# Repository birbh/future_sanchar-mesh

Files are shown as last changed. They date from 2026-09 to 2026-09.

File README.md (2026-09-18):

# future_sanchar-jaal

Future_sanchar-jaal is a custom, open-source digital walkie-talkie powered by ESP32-S3. Unlike traditional analog radios those suffer from static or require a central router to work, this device uses the ESP-NOW v2 protocol to create a direct p2p 2.4GHz network. 

## What makes it unique??
It is unique because it used i2s components alongside a massive 1440 bytes transmission buffer which helps to deliver a crisp voice with an ultra-low latency. Also it uses esp32-S3-wroom-1u which has ipex antenna connector in it which has drastically helped to increase the range of walkie talkie. It provides upto 800+ meters range under normal conditions and if with obstacles it provides upto 200 meters range. 

## Why I made it??

Recently my country Nepal suffered a devastating flood which ruined so many human lives. So I thought that if I could make a Lo-Ra walkie-talkie, I could warn the people using the walkie-talkie along the long distance. Also in Nepal, due to difficult geography, the cellular network coverage could be unreliable when trekking and traveling through rural areas. In conclusion, I made this walkie-talkie to solve the real-world problem and help communicate over long distances easily. 

## How to use it?
1. Turn on the slide switch on the front side of the walkie-talkie.
2. The LED will flash Blue when booting and OLED will display "Sanchar-Jaal Boot".
3. Once the screen displays "Talk!! I am Listening..", you are ready and connected to the network.
4. Then press and hold the Push to Talk button in the front then the led will turn RED, and the screen will display "Transmitting.....!". Then you should speak near the microphone grill.
5. We will have paired devices, so when one talks the LED will turn GREEN and audio will automatically play through the speaker in front.
6. If the walkie talkie glitches then there is reset button in the back why can press that to fix the walkie talkie.
7. If the battery finishes then you can charge it through usb c in the left of walkie talkie
8. You can adjust the volume also from the onboard potentiometer to make the desired volume.

## Assembly Instructions:
### 3d print enclosure:
- All cad files are provided in the github repo.
- there are 3 separate cad files to be printed top lid, bottom lid and the base.
- You should print those 3 files separately

### PCB & soldering:
- All required files are provided in Production folder inside pcb_sanchar.
- solder all the smd components first as indicated in silkscreen
- then solder the usb-c breakout board to its assembly place in the left of walkie talkie using a wire i.e connect In+ and In- of tp4056 to the breakout board VBUS and GND respectively.
- then secure all the components in their respective mounts as in CAD. 

### Flashing firmware:
- Connect your FDTI adapter to J1 programming header on the board.
- Open the firmware file in the arduino ide.
- Hit upload -- when the console says connecting hold the BOOT button in the pcb and Press and release the RESET button then release the boot button.
- Wait for upload to finish then press BOOT button to boot the device.
- Then to pair the two devices check the serial monitor and find the MAC-address of DEVICE 1 and paste it into the code for DEVICE 2 (and vice versa). 

## Assets:
### Cad Screenshots:
Screenshot 2026-09-18 at 1 24 17 PM
Screenshot 2026-09-18 at 1 24 32 PM
Screenshot 2026-09-18 at 1 24 58 PM
Screenshot 2026-09-18 at 1 25 28 PM

### CAD link:
fusion360 ::: [Sanchar-jaal-cad](https://a360.co/4xBj2PT)

### Pcb:
Screenshot 2026-09-18 at 1 17 54 PM
Screenshot 2026-09-18 at 1 18 21 PM
Screenshot 2026-09-18 at 1 18 38 PM

### Schematic:
Screenshot 2026-09-18 at 1 19 46 PM

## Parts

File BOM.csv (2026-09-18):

Id | Designator | Footprint | Quantity | Designation | Link | Price
1 | BT1 | JST_PH_S2B-PH-K_1x02_P2.00mm_Horizontal | 4 | Battery_Cell | https://shorturl.at/hIcLj | $18
2 | C1, C2, C5 | C_0805_2012Metric | 6 | 10µF | https://shorturl.at/dkd7K | $2.3
3 | C3, C4, C6 | C_0805_2012Metric | 6 | 100nf | https://shorturl.at/dkd7K | $2.3
4 | C7 | C_0805_2012Metric | 2 | 1µF | https://shorturl.at/dkd7K | $2.3
5 | D1 | LED_WS2812B_PLCC4_5.0x5.0mm_P3.2mm | 2 | WS2812B | https://shorturl.at/Q40h6 | $11
6 | J1 | FanPinHeader_1x04_P2.54mm_Vertical | 2 | Conn_01x04_Pin | https://shorturl.at/0AHKv | $7
7 | LS1 | JST_PH_S2B-PH-K_1x02_P2.00mm_Horizontal | 2 | Speaker | https://shorturl.at/RXhoH | $5
8 | M1 | INMP441_OMNIDIRECTIONAL_MICROPHONE_MODULE | 2 | INMP441 Microphone | https://h1.nu/1ydcw | $8
9 | R1 | R_0805_2012Metric | 2 | 100kΩ | https://h1.nu/1ydd0 | $1
10 | R2 | R_0805_2012Metric | 2 | 10kΩ | https://h1.nu/1ydd0 | $1
11 | RV1 | Potentiometer_Bourns_PTV09A-1_Single_Vertical | 2 | R_Potentiometer_MountingPin | https://h1.nu/1yddz | $2.9
12 | SW1, SW3-boot, SW4-reset | SW_Push_1P1T_NO_E-Switch_TL3301NxxxxxG | 6 | SW_Push | https://h1.nu/1ydel | $9
13 | SW2 | SW_Slide_SPDT_Straight_CK_OS102011MS2Q | 2 | SW_SPDT | https://h1.nu/1DZo9 | $4.5
14 | TP1 | TP4056-18650 | 2 | TP4056_cm | https://h1.nu/1DZoD | $3.5
15 | U1 | XCVR_ESP32-S3-WROOM-1U-N16R8 | 2 | ESP32-S3-WROOM-1U-N16R8 | https://h1.nu/1ydgw | $9.86
16 | U2 | ER_OLEDM0.91_1x-I2C | 2 | ER_OLEDM0.91_1x-I2C | https://h1.nu/1ydh5 | $6.88
17 | U3 | SOT-223-3_TabPin2 | 2 | AMS1117-3.3 | https://h1.nu/1DZr0 | $6
18 | U4 | TQFN-16-1EP_3x3mm_P0.5mm_EP1.23x1.23mm | 2 | MAX98357A | https://h1.nu/1ydjG | $2.65
19 |  |  | 2 | USB Type C Connector Board 3.1 Serial Basic Breakout Female | https://h1.nu/1DZtC | $4.99
20 |  |  | 2 | JST_PH | https://h1.nu/1DZvK | $.24
 | TOTAL |  |  |  |  | $108.42

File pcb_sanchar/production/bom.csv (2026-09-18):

Designator | Footprint | Quantity | Value | LCSC Part #
BT1 | JST_PH_S2B-PH-K_1x02_P2.00mm_Horizontal | 1 | Battery_Cell
C1, C2, C5 | 0805 | 3 | 10µF
C3, C4, C6 | 0805 | 3 | 100nf
C7 | 0805 | 1 | 1µF
D1 | LED_WS2812B_PLCC4_5.0x5.0mm_P3.2mm | 1 | WS2812B
J1 | FanPinHeader_1x04_P2.54mm_Vertical | 1 | Conn_01x04_Pin
LS1 | JST_PH_S2B-PH-K_1x02_P2.00mm_Horizontal | 1 | Speaker
M1 | INMP441_OMNIDIRECTIONAL_MICROPHONE_MODULE | 1 | INMP441 Microphone
R1 | 0805 | 1 | 100kΩ
R2 | 0805 | 1 | 10kΩ
RV1 | Potentiometer_Bourns_PTV09A-1_Single_Vertical | 1 | R_Potentiometer_MountingPin
SW1, SW3-BOOT, SW4-RESET | SW_Push_1P1T_NO_E-Switch_TL3301NxxxxxG | 3 | SW_Push
SW2 | SW_Slide_SPDT_Straight_CK_OS102011MS2Q | 1 | SW_SPDT
TP1 | TP4056-18650 | 1 | TP4056_cm
U1 | XCVR_ESP32-S3-WROOM-1U-N16R8 | 1 | ESP32-S3-WROOM-1U-N16R8
U2 | ER_OLEDM0.91_1x-I2C | 1 | ER_OLEDM0.91_1x-I2C
U3 | SOT-223-3_TabPin2 | 1 | AMS1117-3.3
U4 | TQFN-16-1EP_3x3mm_P0.5mm_EP1.23x1.23mm | 1 | MAX98357A

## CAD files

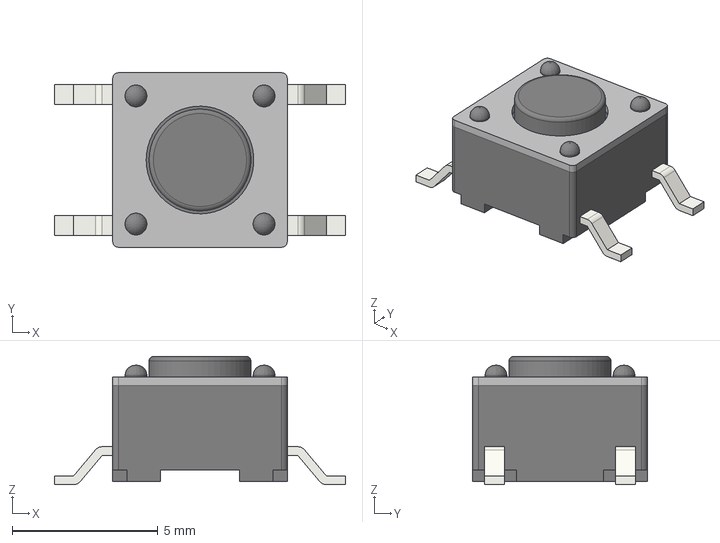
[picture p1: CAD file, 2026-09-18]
CAD/parts/SW_Push_1P1T_NO_E-Switch_TL3301NxxxxxG.step
10.0 x 6.00 x 4.40 mm

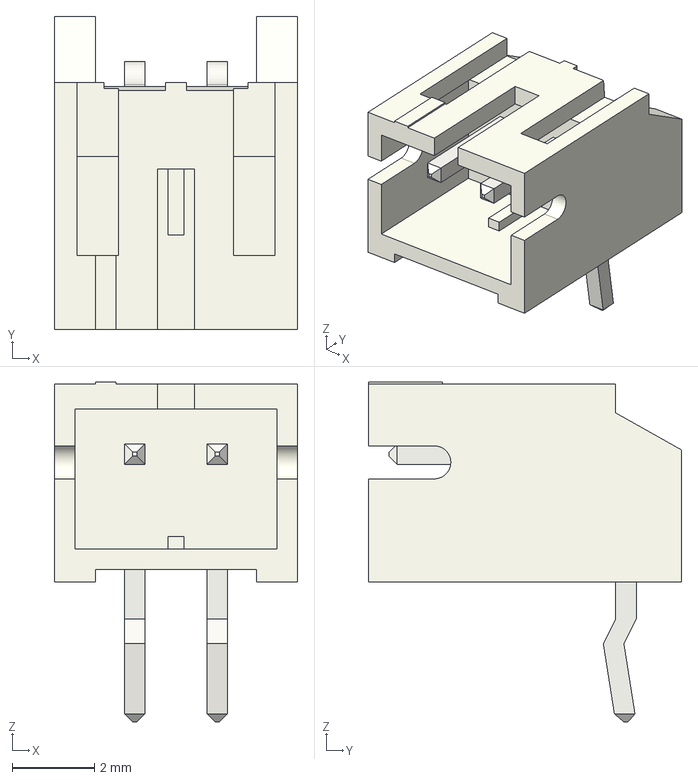
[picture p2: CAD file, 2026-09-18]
CAD/parts/JST_PH_S2B-PH-K_1x02_P2.00mm_Horizontal.step
5.90 x 7.60 x 8.25 mm

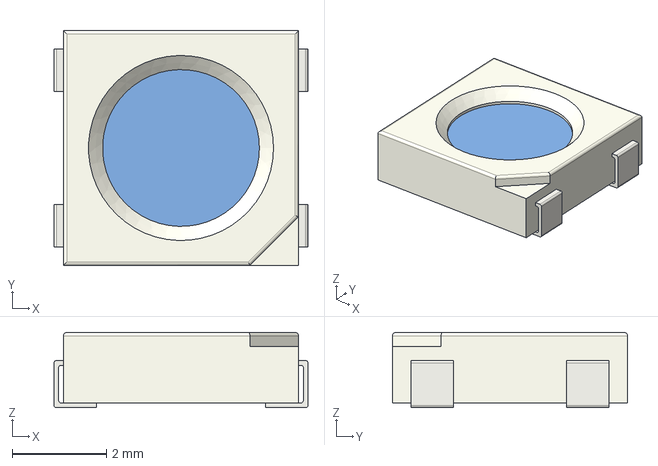
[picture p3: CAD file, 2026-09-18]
CAD/parts/LED_WS2812B_PLCC4_5.0x5.0mm_P3.2mm.step
5.40 x 5.00 x 1.60 mm

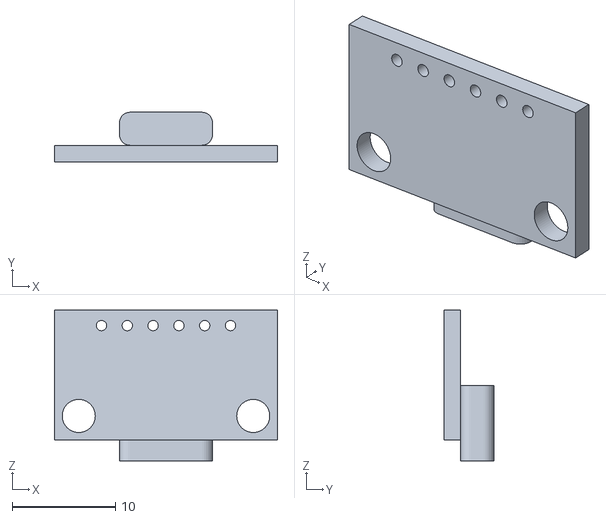
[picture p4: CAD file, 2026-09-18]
CAD/parts/usb-c-breakout.obj
21.6 x 4.80 x 14.6

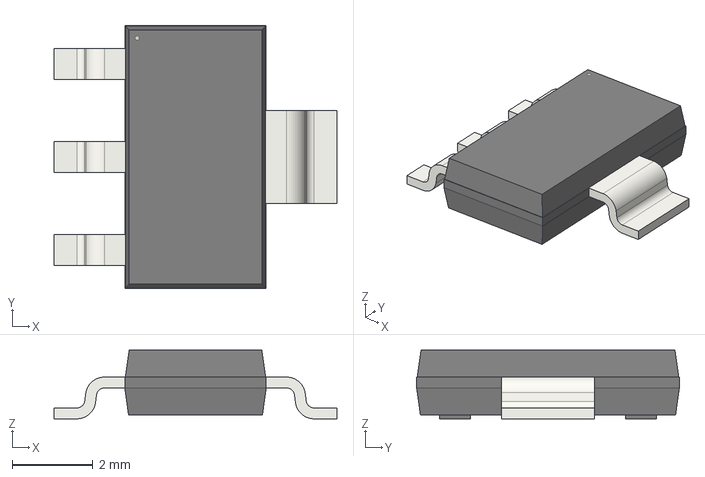
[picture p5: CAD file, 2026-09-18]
CAD/parts/SOT-223.step
7.00 x 6.50 x 1.70 mm

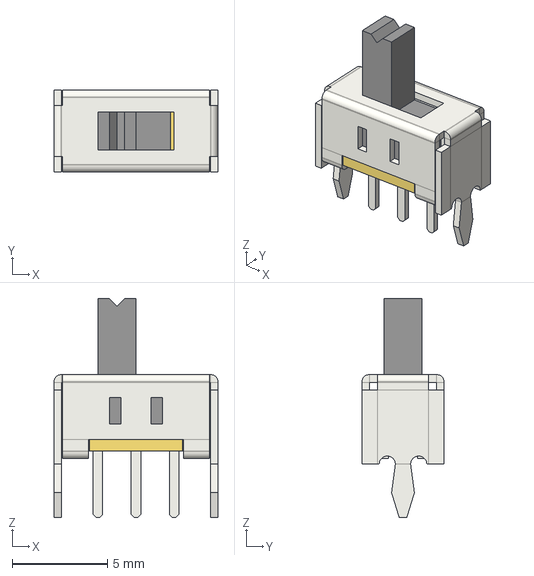
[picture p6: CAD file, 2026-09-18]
CAD/parts/SW_Slide_SPDT_Straight_CK_OS102011MS2Q.step
8.60 x 4.30 x 11.5 mm

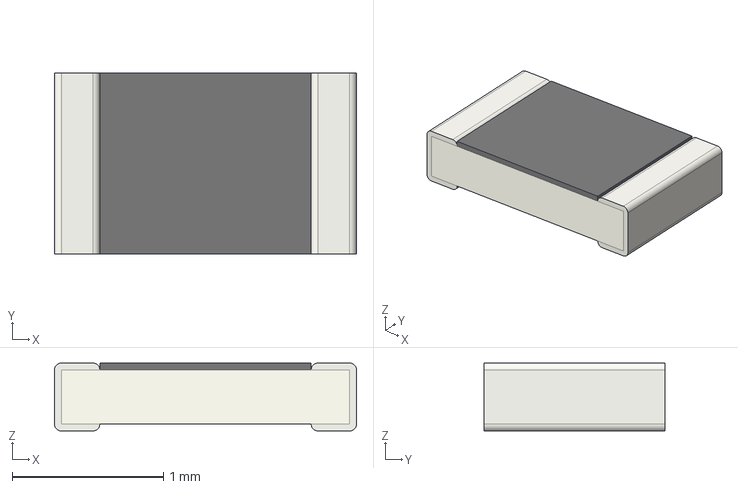
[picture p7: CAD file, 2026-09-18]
CAD/parts/R_0805_2012Metric.step
2.00 x 1.20 x 0.45 mm

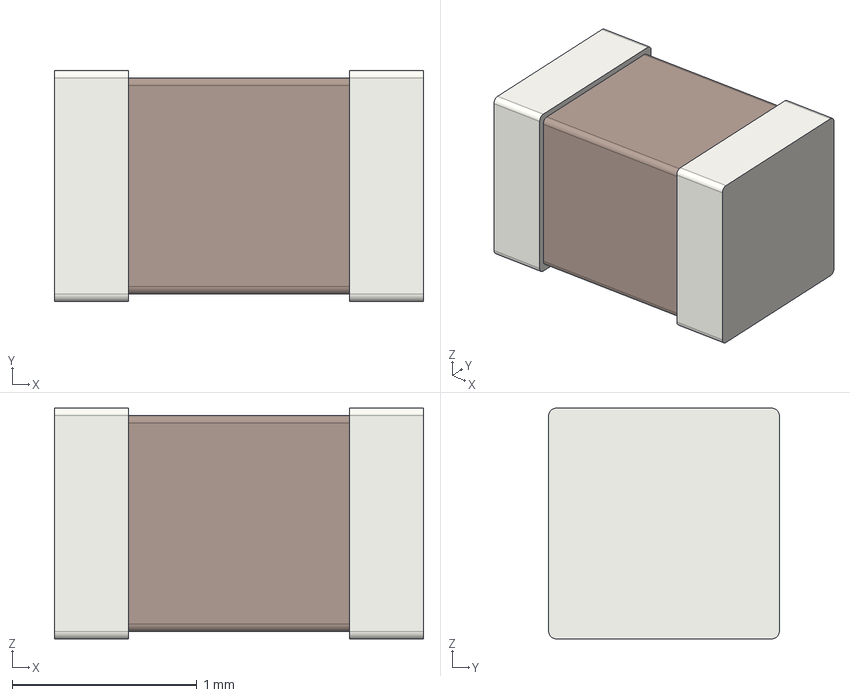
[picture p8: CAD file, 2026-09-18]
CAD/parts/C_0805_2012Metric.step
2.00 x 1.25 x 1.25 mm

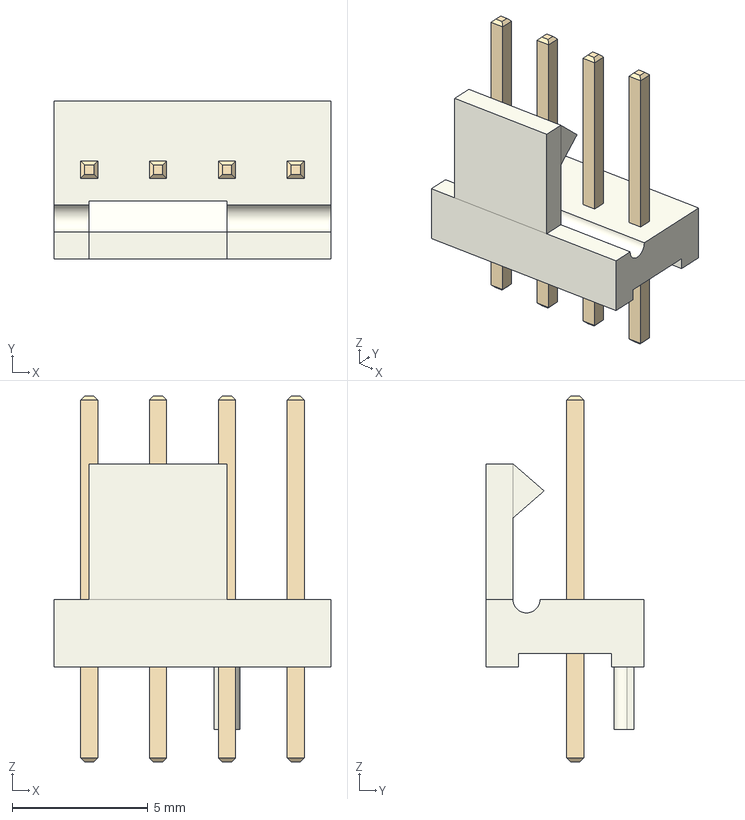
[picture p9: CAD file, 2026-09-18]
CAD/parts/FanPinHeader_1x04_P2.54mm_Vertical.step
10.2 x 5.84 x 13.5 mm

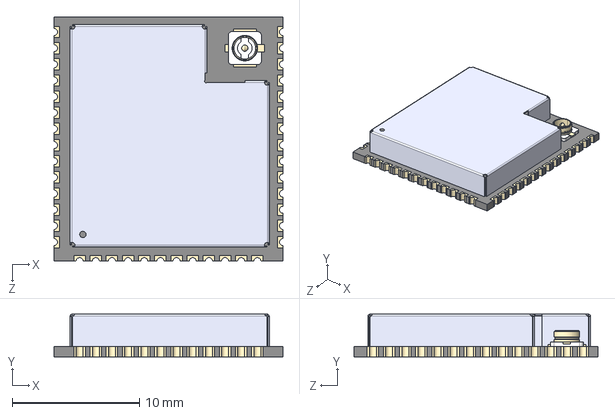
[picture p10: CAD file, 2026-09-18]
CAD/parts/ESP32-S3-WROOM-1U-N16R8.step
18.0 x 3.35 x 19.2 mm

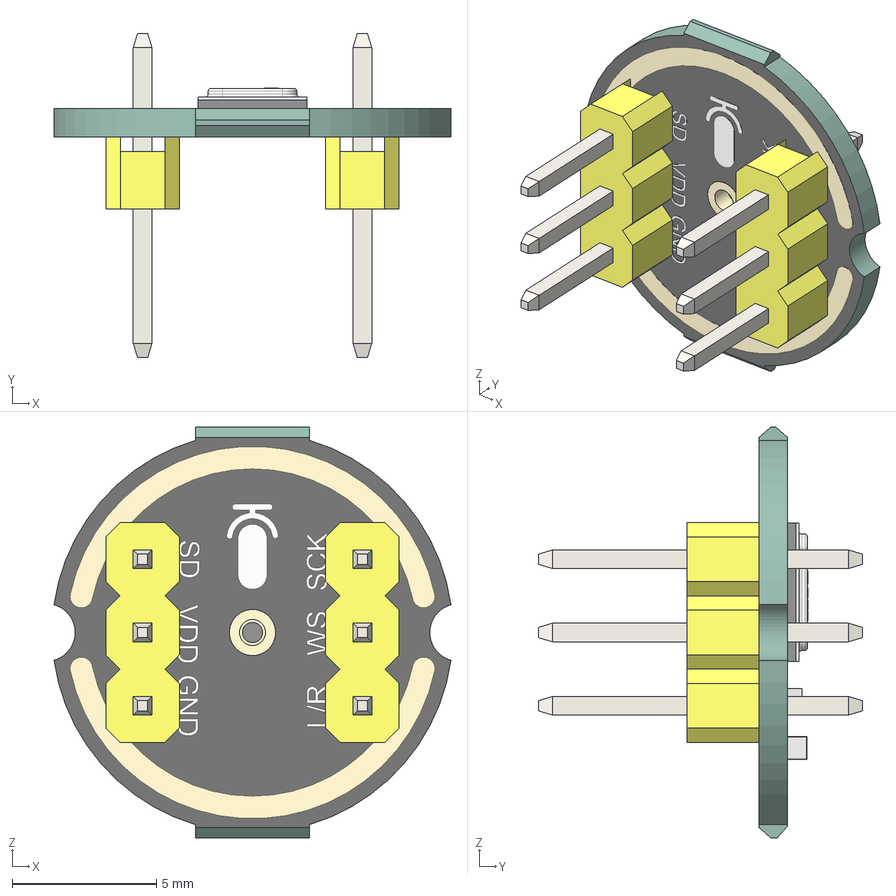
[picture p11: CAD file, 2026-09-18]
CAD/parts/INMP441 I2S Microphone Module v15.step
13.8 x 11.2 x 14.2 mm
0603 Resistor

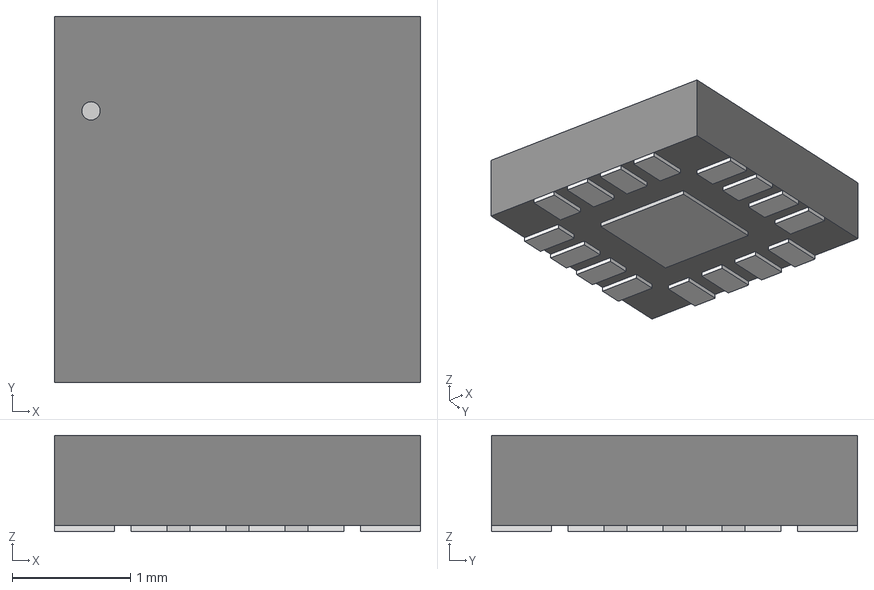
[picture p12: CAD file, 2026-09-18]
CAD/parts/21-0136I_T1633-4_MXM.step
3.10 x 3.10 x 0.815 mm

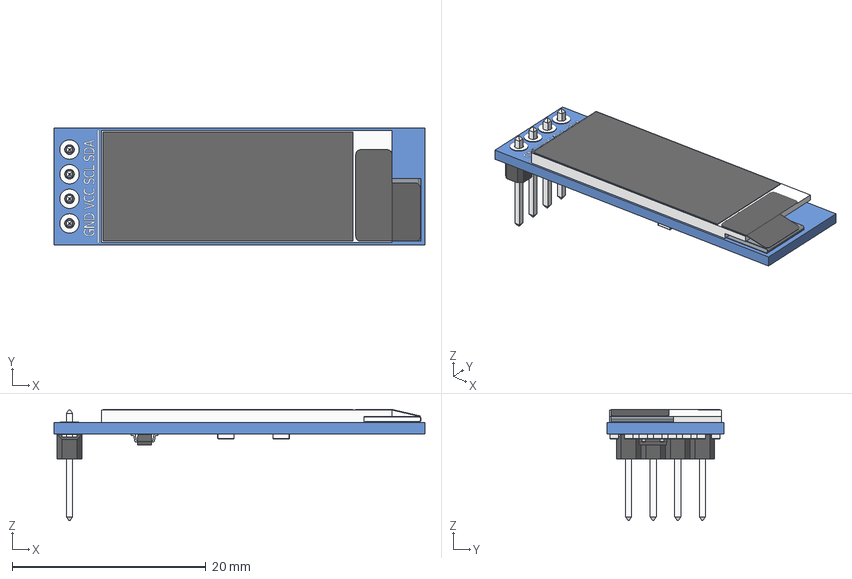
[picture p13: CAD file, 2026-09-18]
CAD/parts/OLED_0.91_128x32.stp
38.3 x 12.1 x 11.5 mm
OLED_0.91_128x32
Pin Header 4 x 1 TH 2.54mm Pitch
RESC-0603 x 13
2SD0601A

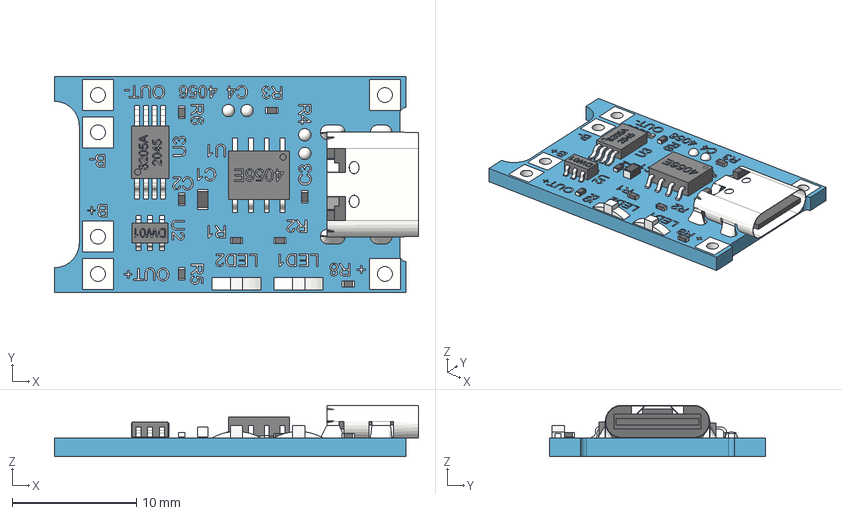
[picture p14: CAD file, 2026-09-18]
CAD/parts/TP4056_Charging_Module_Type_C.step
29.3 x 17.4 x 4.14 mm
board
USB_Type_C_Connector
8205A_2045
DW01-P
small1005_smd_resistor x 2
small1005_smd_resistor (1)
small1005_smd_capacitor
smd_capacitor
SOP-8_4056E
solder_dot_round
solder_dot_round (1)
solder_dot_round (2)
solder_dot_round (3)
small1005_smd_capacitor (1)
LED2
LED2 (1)
small1005_smd_resistor (2)
small1005_smd_resistor (4) x 2
soldering

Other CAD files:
CAD/3D print/back-lid.f3d
CAD/3D print/base.f3d
CAD/3D print/top-lid.f3d

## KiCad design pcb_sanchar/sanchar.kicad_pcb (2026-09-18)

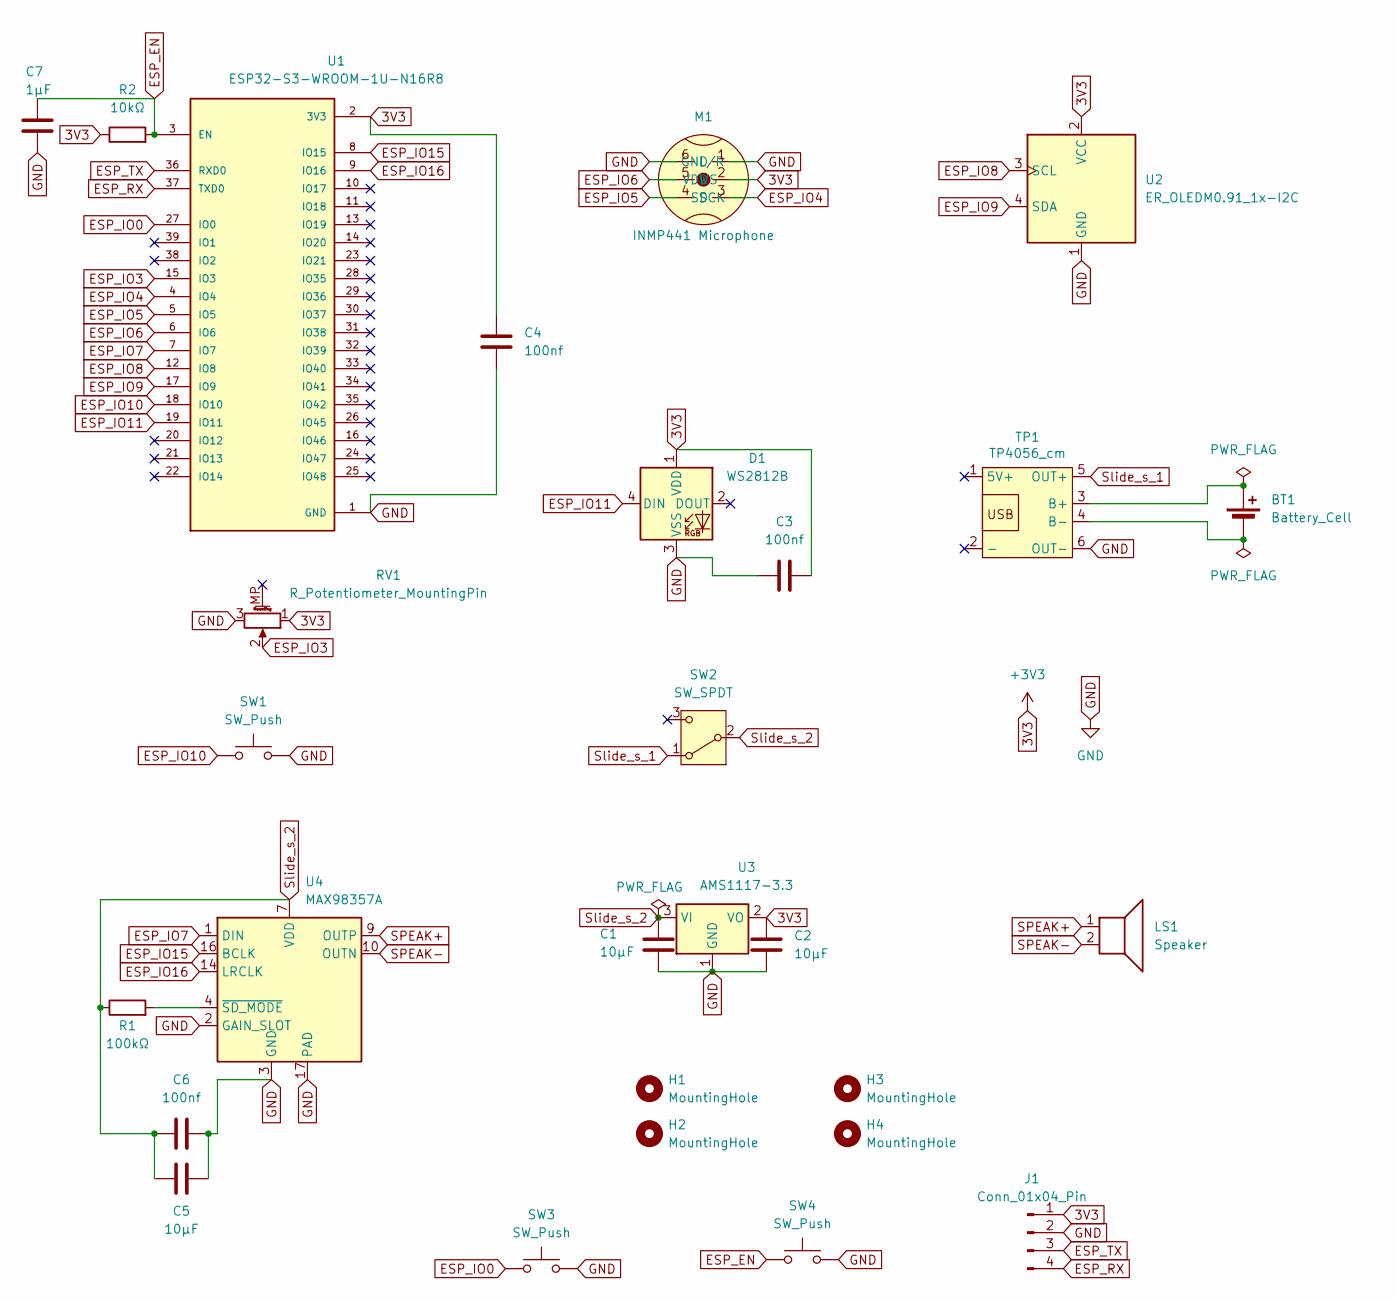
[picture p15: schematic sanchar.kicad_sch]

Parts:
BT1: Battery_Cell; JST_PH_S2B-PH-K_1x02_P2.00mm_Horizontal
C1, C2, C5: 10µF; C_0805_2012Metric
C3, C4, C6: 100nf; C_0805_2012Metric
C7: 1µF; C_0805_2012Metric
D1: WS2812B; LED_WS2812B_PLCC4_5.0x5.0mm_P3.2mm
H1, H2, H3, H4: MountingHole; MountingHole_3.2mm_M3
J1: Conn_01x04_Pin; FanPinHeader_1x04_P2.54mm_Vertical
LS1: Speaker; JST_PH_S2B-PH-K_1x02_P2.00mm_Horizontal
M1: INMP441 Microphone; INMP441_OMNIDIRECTIONAL_MICROPHONE_MODULE
R1: 100kΩ; R_0805_2012Metric
R2: 10kΩ; R_0805_2012Metric
RV1: R_Potentiometer_MountingPin; Potentiometer_Bourns_PTV09A-1_Single_Vertical
SW1, SW3, SW4: SW_Push; SW_Push_1P1T_NO_E-Switch_TL3301NxxxxxG
SW2: SW_SPDT; SW_Slide_SPDT_Straight_CK_OS102011MS2Q
TP1: TP4056_cm; TP4056-18650
U1: ESP32-S3-WROOM-1U-N16R8; XCVR_ESP32-S3-WROOM-1U-N16R8; PARTREV v1.1
U2: ER_OLEDM0.91_1x-I2C
U3: AMS1117-3.3; SOT-223-3_TabPin2
U4: MAX98357A; TQFN-16-1EP_3x3mm_P0.5mm_EP1.23x1.23mm

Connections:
3V3: C2.1, C3.2, C4.1, D1.1 (VDD), J1.1, M1.2 (VDD), R2.1, RV1.1, U1.2 (3V3), U2.2 (VCC), U3.2 (VO)
ESP_EN: C7.1, R2.2, SW4.1, U1.3 (EN); also elsewhere on the board
ESP_IO0: SW3.1, U1.27 (IO0); also elsewhere on the board
ESP_IO3: RV1.2, U1.15 (IO3)
ESP_IO4: M1.3 (SD), U1.4 (IO4)
ESP_IO5: M1.4 (SCK), U1.5 (IO5)
ESP_IO6: M1.5 (WS), U1.6 (IO6)
ESP_IO7: U1.7 (IO7), U4.1 (DIN)
ESP_IO8: U1.12 (IO8), U2.3 (SCL)
ESP_IO9: U1.17 (IO9), U2.4 (SDA)
ESP_IO10: SW1.1, U1.18 (IO10)
ESP_IO11: D1.4 (DIN), U1.19 (IO11)
ESP_IO15: U1.8 (IO15), U4.16 (BCLK)
ESP_IO16: U1.9 (IO16), U4.14 (LRCLK)
ESP_RX: J1.4, U1.37 (TXD0)
ESP_TX: J1.3, U1.36 (RXD0)
GND: C1.2, C2.2, C3.1, C4.2, C5.2, C6.2, C7.2, D1.3 (VSS), J1.2, M1.1 (GND), M1.6 (L/R), RV1.3, SW1.2, SW3.2, SW4.2, TP1.6 (OUT-), U1.1 (GND), U1.40 (GND), U1.41_1 (GND), U1.41_2 (GND), U1.41_3 (GND), U1.41_4 (GND), U1.41_5 (GND), U1.41_6 (GND), U1.41_7 (GND), U1.41_8 (GND), U1.41_9 (GND), U1.41_10, U1.41_11, U1.41_12, U1.41_13, U1.41_14, U1.41_15, U1.41_16, U1.41_17, U1.41_18, U1.41_19, U1.41_20, U1.41_21, U2.1 (GND), U3.1 (GND), U4.2 (GAIN_SLOT), U4.3 (GND), U4.11 (GND), U4.15 (GND), U4.17 (PAD); also elsewhere on the board
unnamed: BT1.1 (+), TP1.3 (B+)
unnamed: BT1.2 (-), TP1.4 (B-)
unnamed: R1.2, U4.4 (~SD_MODE)
SPEAK+: LS1.1, U4.9 (OUTP)
SPEAK-: LS1.2, U4.10 (OUTN)
Slide_s_1: SW2.1 (A), TP1.5 (OUT+)
Slide_s_2: C1.1, C5.1, C6.1, R1.1, SW2.2 (B), U3.3 (VI), U4.7 (VDD), U4.8 (VDD)

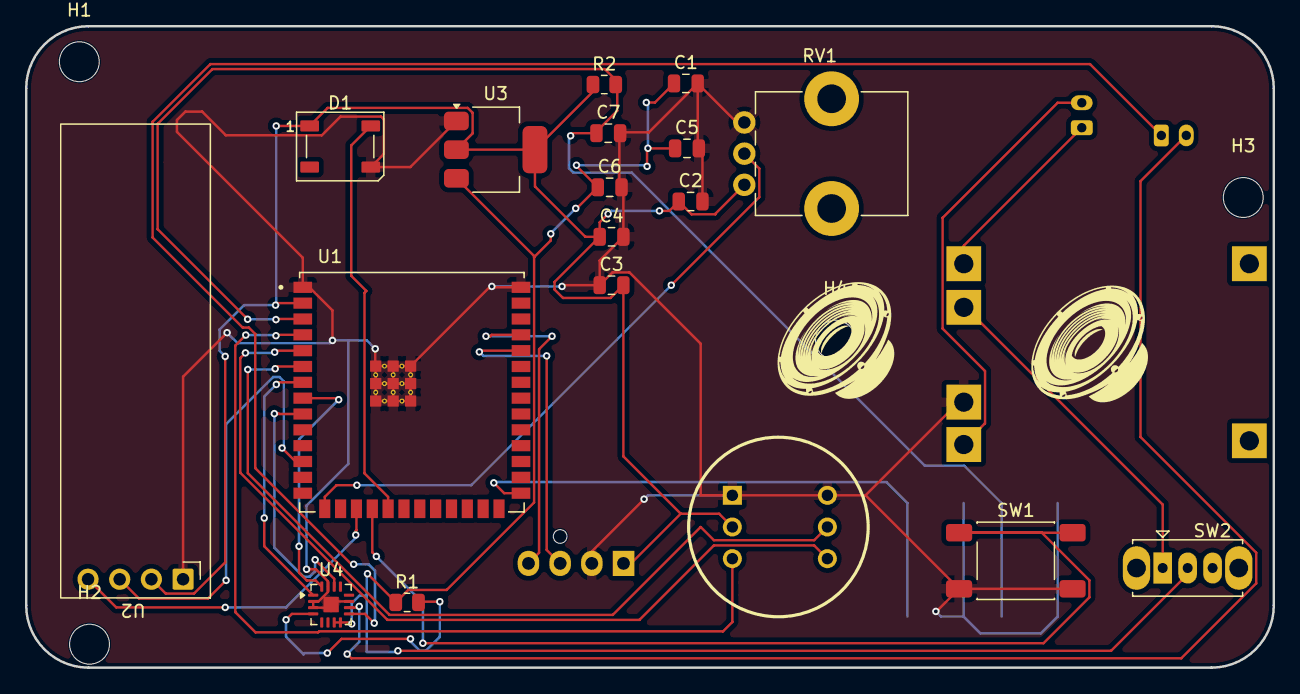
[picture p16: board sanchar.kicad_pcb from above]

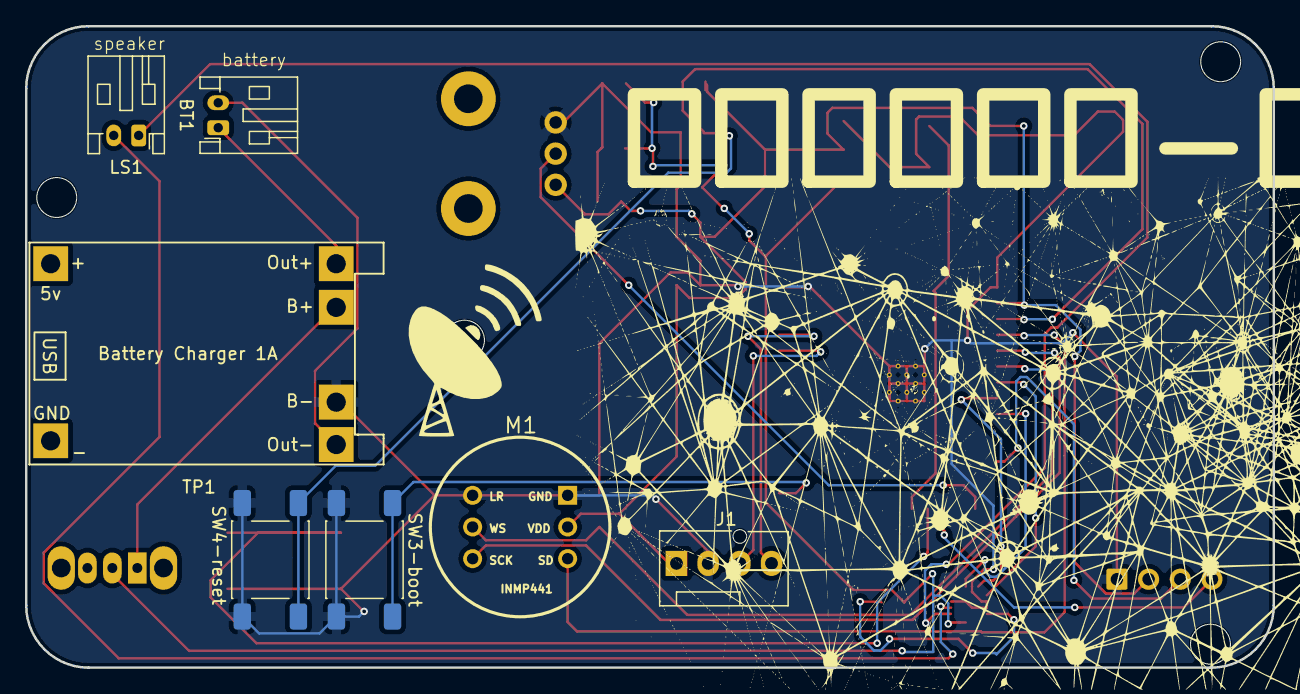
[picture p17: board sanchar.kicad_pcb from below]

Board: 2 copper layers, 100.1 x 51.4 mm, 28 parts (7 on the bottom side), 24 nets.

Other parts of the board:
SW3-boot, SW4-reset: SW_Push; SW_Push_1P1T_NO_E-Switch_TL3301NxxxxxG

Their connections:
ESP_EN: SW4-reset.1; also elsewhere on the board
ESP_IO0: SW3-boot.1; also elsewhere on the board
GND: SW3-boot.2, SW4-reset.2; also elsewhere on the board

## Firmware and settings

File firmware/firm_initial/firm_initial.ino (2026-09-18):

#include <WiFi.h>
#include <esp_now.h>
#include <driver/i2s.h>
#include <Wire.h>
#include <FastLED.h>
#include <Adafruit_GFX.h>
#include <Adafruit_SSD1306.h>

// pin defs. 
#define I2C_SDA 9
#define I2C_SCL 8
#define LED_DIN 11
#define POTENT_PIN 3
#define PUSH_SPEAK 10

// INMP441 Microphone
#define MIC_SCK 5
#define MIC_WS 6
#define MIC_SD 4

// MAX98357A amp
#define AMP_DIN 7
#define AMP_BCLK 15
#define AMP_LRCK 16

//peripherals
#define SC_WIDTH 128
#define SC_HEIGHT 32
Adafruit_SSD1306 display(SC_WIDTH, SC_HEIGHT, &Wire, -1);
CRGB leds[1];



//esp-now rf comms. 
//  ESP32 receiver MAC address
uint8_t broadcastAddress[] = {0x30, 0xAE, 0xA4, 0x07, 0x0D, 0x64}; // change to receiver mac addr. 
esp_now_peer_info_t peerInfo;
// sys_state & audio
bool transmitting=false;
#define AUDIO_SIZE 1440
uint8_t audioBuffer[AUDIO_SIZE];

//protoype
void updatemsg(String);
void i2sInit();
void sendAudio();
void onRecieve(const esp_now_recv_info_t *info, const uint8_t *incomingData, int len);

void setup() {
  Serial.begin(115200);

  //init ui
  pinMode(PUSH_SPEAK, INPUT_PULLUP);
  pinMode(POTENT_PIN, INPUT);

  FastLED.addLeds<WS2812B, LED_DIN, GRB>(leds,1);
  leds[0]= CRGB::Blue;
  FastLED.show();

  Wire.begin(I2C_SDA,I2C_SCL);
  if(!display.begin(SSD1306_SWITCHCAPVCC,0x3C)){
    Serial.println("OLED START FAIL!!");
  }
  else{
    updatemsg("Sanchar-Jaal Boot");
  }

  //init. espnow
  WiFi.mode(WIFI_STA);
  if(esp_now_init()!=ESP_OK){
    Serial.println("Error ESP-NOW communication");
    return;
  }
  memcpy(peerInfo.peer_addr, broadcastAddress,6);
  peerInfo.channel=0;
  peerInfo.encrypt=false;
  esp_now_add_peer(&peerInfo);
  esp_now_register_recv_cb(onRecieve);

  // ini. audio
  i2sInit();

  //boot success
  //listening ready
  leds[0]= CRGB::Black;
  FastLED.show();
  updatemsg("Talk!! I am Listening..");

}

void loop() {
  //read pust-to-talk buttons
  bool talkbutt= (digitalRead(PUSH_SPEAK)==LOW);
  if (talkbutt && !transmitting){
    transmitting=true;
    leds[0]= CRGB::Red;
    FastLED.show();
    updatemsg("Transmitting.....!");
  }
  else if(!talkbutt && transmitting){
    transmitting=false;
    leds[0]= CRGB::Black;
    FastLED.show();
    updatemsg("Listening.....!");
  }

  //capture mic audio..send
  if(transmitting){
    sendAudio();
  }
  else{
    delay(2);
  }

}

void updatemsg(String msg) {
  display.clearDisplay();
  display.setTextColor(SSD1306_WHITE);
  display.setTextSize(1);
  display.setCursor(0,0);
  display.println("Channel: 1");
  display.setCursor(0,16);
  display.println(msg);
  display.display();
}

void i2sInit() {
  //config. i2s port mic
  i2s_config_t i2s_mic_config = {
    .mode = (i2s_mode_t)(I2S_MODE_MASTER | I2S_MODE_RX),
    .sample_rate = 16000,
    .bits_per_sample = I2S_BITS_PER_SAMPLE_16BIT,
    .channel_format = I2S_CHANNEL_FMT_ONLY_LEFT,
    .communication_format = I2S_COMM_FORMAT_STAND_I2S,
    .intr_alloc_flags = ESP_INTR_FLAG_LEVEL1,
    .dma_buf_count = 8,
    .dma_buf_len = 720,
    .use_apll = false,
  };

  const i2s_pin_config_t MIC_pin_config = {
    .bck_io_num = MIC_SCK,
    .ws_io_num = MIC_WS,
    .data_out_num = I2S_PIN_NO_CHANGE,
    .data_in_num = MIC_SD
  };

  i2s_driver_install(I2S_NUM_0, &i2s_mic_config, 0, NULL);
  i2s_set_pin(I2S_NUM_0, &MIC_pin_config);

  // config. i2s port for speaker
  i2s_config_t i2s_amp_config = {
    .mode = (i2s_mode_t)(I2S_MODE_MASTER | I2S_MODE_TX),
    .sample_rate = 16000,
    .bits_per_sample = I2S_BITS_PER_SAMPLE_16BIT,
    .channel_format = I2S_CHANNEL_FMT_ONLY_LEFT,
    .communication_format = I2S_COMM_FORMAT_STAND_I2S,
    .intr_alloc_flags = ESP_INTR_FLAG_LEVEL1,
    .dma_buf_count = 8,
    .dma_buf_len = 720,
    .use_apll = false,
  };

  const i2s_pin_config_t AMP_pin_config = {
    .bck_io_num = AMP_BCLK,
    .ws_io_num = AMP_LRCK,
    .data_out_num = AMP_DIN,
    .data_in_num = I2S_PIN_NO_CHANGE
  };

  i2s_driver_install(I2S_NUM_1, &i2s_amp_config, 0, NULL);
  i2s_set_pin(I2S_NUM_1, &AMP_pin_config);
}

void sendAudio() {
  size_t bytesRead;
  // inmp441 raw audio buffer
  esp_err_t res = i2s_read(I2S_NUM_0, audioBuffer, AUDIO_SIZE, &bytesRead, portMAX_DELAY);
  if(res == ESP_OK && bytesRead > 0) {
     esp_now_send(broadcastAddress, audioBuffer, bytesRead);
  }
}

// WHEN TALKING STOP PLAYING AUDIO SO THAT HALF-DUPLEX MODE APPLIES, AMPLIFY, LED ON
void onRecieve(const esp_now_recv_info_t *info, const uint8_t *incomingData, int len) {
  if(transmitting) return;
  
  leds[0] = CRGB::Green;
  FastLED.show();

  // read potent.(0-4095 esp le read garcha) 
  float volmull= analogRead(POTENT_PIN)/4095;

  //crete output buffer
  uint8_t outgoingdata[AUDIO_SIZE];

  //DONE WITH AI

  // Cast the raw bytes into 16-bit audio numbers so we can do math on them
  int16_t *incomingSamples = (int16_t *)incomingData;
  int16_t *adjustedSamples = (int16_t *)outputBuffer;
  
  // Calculate how many 16-bit samples are in this packet (length / 2)
  int numSamples = len / 2; 

  // 3. Multiply every single audio sample by our volume fraction
  for (int i = 0; i < numSamples; i++) {
    adjustedSamples[i] = incomingSamples[i] * volmull;
  }

  // 


  // END  AI

  size_t bytes_written;
  // transmit to amp. 
  i2s_write(I2S_NUM_1, outgoingdata, len, &bytes_written, portMAX_DELAY);

  leds[0] = CRGB::Black;
  FastLED.show();
}

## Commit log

2026-09-18 Revise README for future_sanchar-jaal project
    Updated project name and added detailed description, usage instructions, assembly instructions, and asset links for the future_sanchar-jaal project.
2026-09-18 Add cad files
    [21-0136I_T1633-4_MXM.step, C_0805_2012Metric.step, ESP32-S3-WROOM-1U-N16R8.step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]
